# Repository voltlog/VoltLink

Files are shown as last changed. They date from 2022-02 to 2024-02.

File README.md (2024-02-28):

# VoltLink™
***If you would like to order one of these adapters ready assembled, check out my [Tindie store](https://www.tindie.com/products/23076/).***

VoltLink™ is a USB to serial adapter board based on the popular CP2102N chip with built-in ESP32 auto-reset circuitry. When compared to the cheap modules you can get from Aliexpress this adapter is reliable & flexible at the same time. Reliable because it's based on a well known usb to serial adapter chip sourced from a known supplier and flexible because you have the ESP32 IO & EN pin auto-reset circuit built-in so there is no need to implement this on the target board.

Another advantage of the VoltLink is the built-in 3.3V 500mA low dropout regulator capable of powering the device your are programming. Optionally you can connect a custom JST cable that alows programming of Shelly relays safely, without mains power. This makes the VoltLink one of the best usb/serial adapters to flash your devices with Tasmota or ESPHome.

You have the option of connecting through the VoltLink connector which is a JST-SH 1.0mm pitch 6 pin connector that saves space on the target board or via standard 0.1 inch pin header. 

More info about this project in [Voltlog #405](https://youtu.be/4uZt7zaJOnc).
> Please note, there have been several board revisions since I made that video.

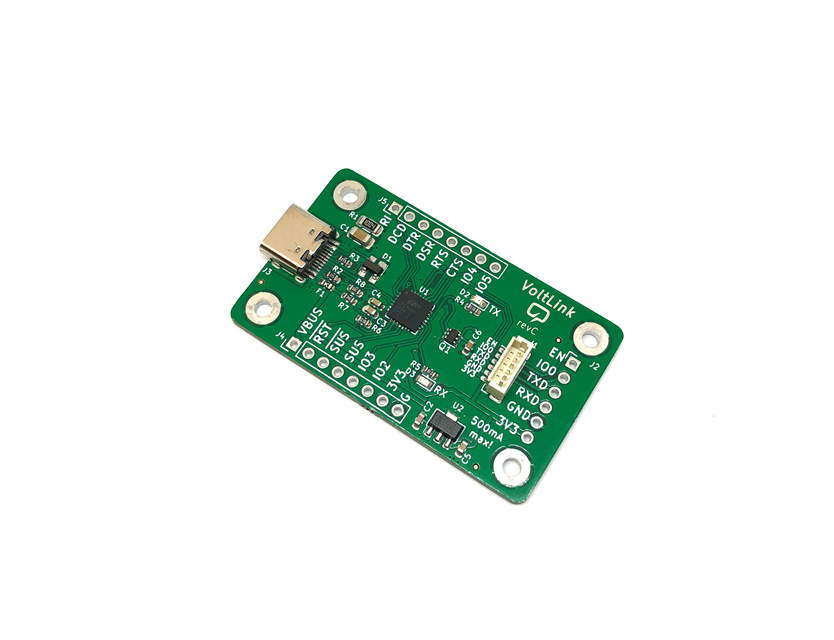
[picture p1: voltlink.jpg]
Image of the assembled PCB


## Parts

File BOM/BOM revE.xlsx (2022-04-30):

VoltLink revD Bill Of Materials
Qty | Reference(s) | Value | Footprint | Datasheet | LCSC | PN
1 | C1 | 4.7nF | Capacitor_SMD:C_1206_3216Metric | ~ | C107198 | CC1206KKX7RCBB472
2 | C2, C4 | 1uF | Capacitor_SMD:C_0603_1608Metric | ~ | C1592 | CL10A105KO8NNNC
2 | C3, C5 | 10uF | Capacitor_SMD:C_0603_1608Metric | ~ | C92487 | CL10A106MO8NQNC
1 | C6 | 0.1uF | Capacitor_SMD:C_0603_1608Metric | ~ | C24452 | CL10B104JB8NNNC
1 | D1 | PWR | LED_SMD:LED_0603_1608Metric | https://datasheet.lcsc.com/lcsc/2008201033_Foshan-NationStar-Optoelectronics-NCD0603R5_C193902.pdf | C193902 | NCD0603R5
1 | D2 | TX | LED_SMD:LED_0603_1608Metric | https://datasheet.lcsc.com/lcsc/2008201032_Foshan-NationStar-Optoelectronics-NCD0603G1_C84267.pdf | C84267 | NCD0603G1
1 | D3 | RX | LED_SMD:LED_0603_1608Metric | https://datasheet.lcsc.com/lcsc/2008201033_Foshan-NationStar-Optoelectronics-NCD0603R5_C193902.pdf | C193902 | NCD0603R5
1 | F1 | 0.5A | Fuse:Fuse_0603_1608Metric | ~ | C207014 | 0603L050SLYR
1 | J1 | Link | Connector_JST:JST_SH_BM06B-SRSS-TB_1x06-1MP_P1.00mm_Vertical | ~ | C145963 | BOOMELE
1 | J2 | Standard | Connector_PinHeader_2.54mm:PinHeader_1x06_P2.54mm_Horizontal | ~
1 | J3 | USB_C_Receptacle_USB2.0 | voltlog:TYPE-C-31-M-12 | https://www.usb.org/sites/default/files/documents/usb_type-c.zip | C165948 | TYPE-C-31-M-12
2 | J4, J5 | Conn_01x08 | Connector_PinHeader_2.54mm:PinHeader_1x08_P2.54mm_Vertical | ~
1 | Q1 | UMH3N | Package_TO_SOT_SMD:SOT-363_SC-70-6 | http://rohmfs.rohm.com/en/products/databook/datasheet/discrete/transistor/digital/emh3t2r-e.pdf | C62892 | UMH3N
1 | R1 | 1M | Resistor_SMD:R_1206_3216Metric | ~
2 | R2, R3 | 5K1 | Resistor_SMD:R_0603_1608Metric | ~
1 | R4 | 22.1K | Resistor_SMD:R_0603_1608Metric | ~
1 | R5 | 47.5K | Resistor_SMD:R_0603_1608Metric | ~
1 | RN1 | 1K | Resistor_SMD:R_Array_Convex_4x0603 | ~ | C425239 | 4D03WGF1001T5E
1 | U1 | LR1107 | Package_TO_SOT_SMD:SOT-89-3 | https://datasheet.lcsc.com/lcsc/1809251634_UTC-Unisonic-Tech-LR1107G-33-AB3-C-R_C171498.pdf | C171498 | LR1107G-33-AB3-C-R
1 | U2 | USBLC6-2P6 | Package_TO_SOT_SMD:SOT-666 | https://www.st.com/resource/en/datasheet/usblc6-2.pdf
1 | U3 | CP2102N-A01-GQFN28 | Package_DFN_QFN:QFN-28-1EP_5x5mm_P0.5mm_EP3.35x3.35mm | https://www.silabs.com/documents/public/data-sheets/cp2102n-datasheet.pdf | C964632 | CP2102N-A02-GQFN28R

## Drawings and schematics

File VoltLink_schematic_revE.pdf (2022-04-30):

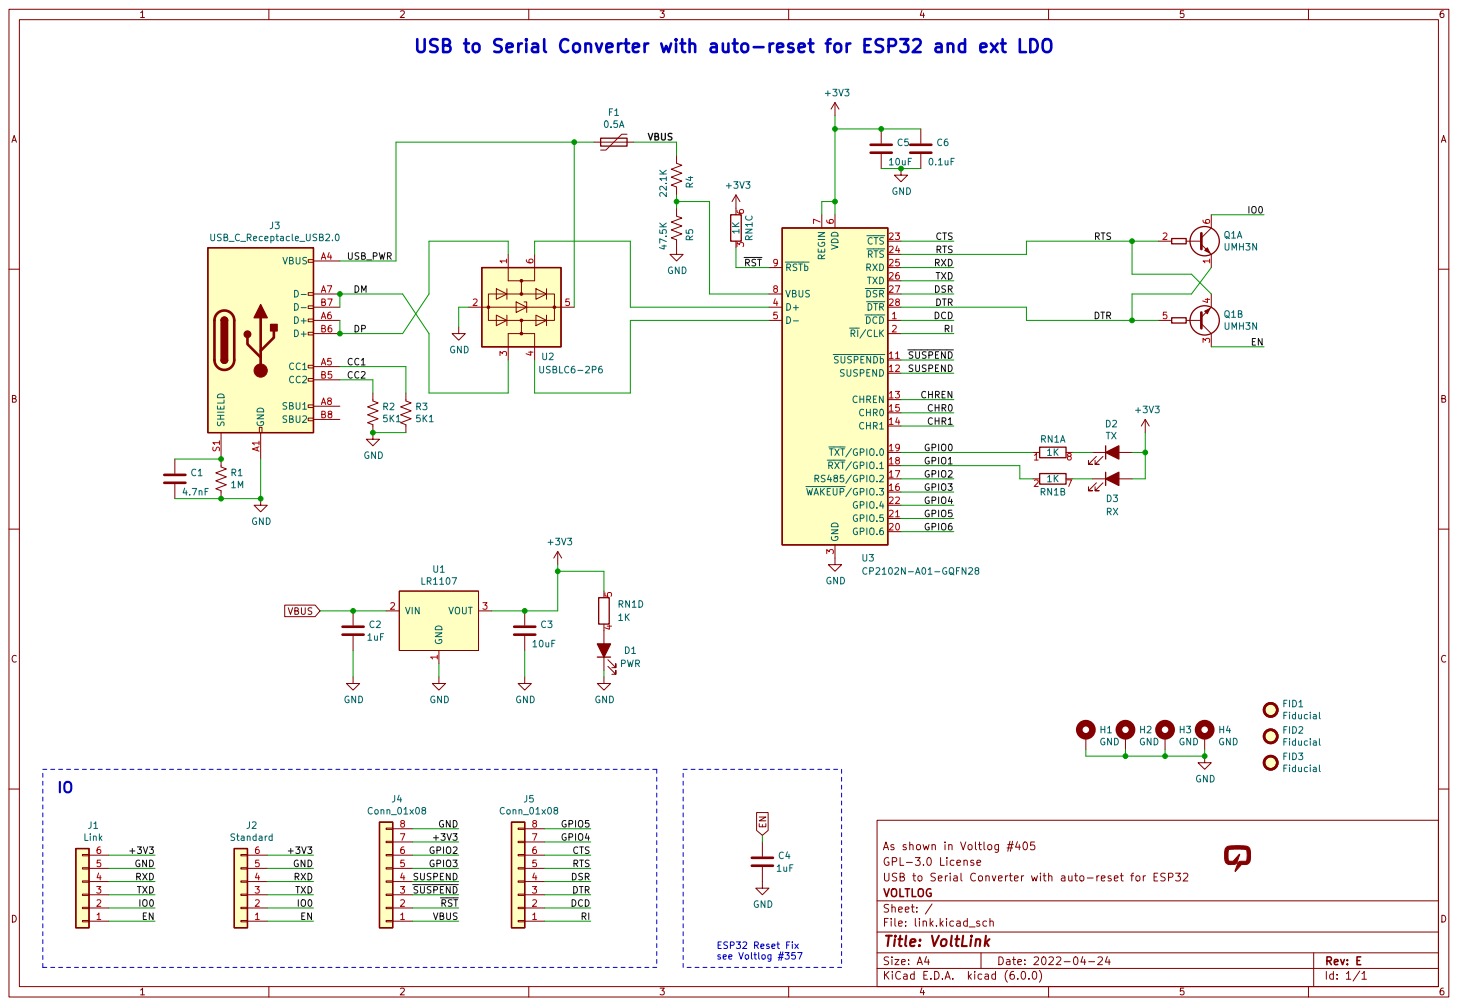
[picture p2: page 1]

USB to Serial Converter with auto-reset for ESP32 and ext LDO

USB to Serial Converter with auto-reset for ESP32 GPL-3.0 License As shown in Voltlog #405

4 | 4 SUSPEND | 4
2 | VBUS 2 | DTR 2

File: link.kicad_sch Sheet: / VOLTLOG

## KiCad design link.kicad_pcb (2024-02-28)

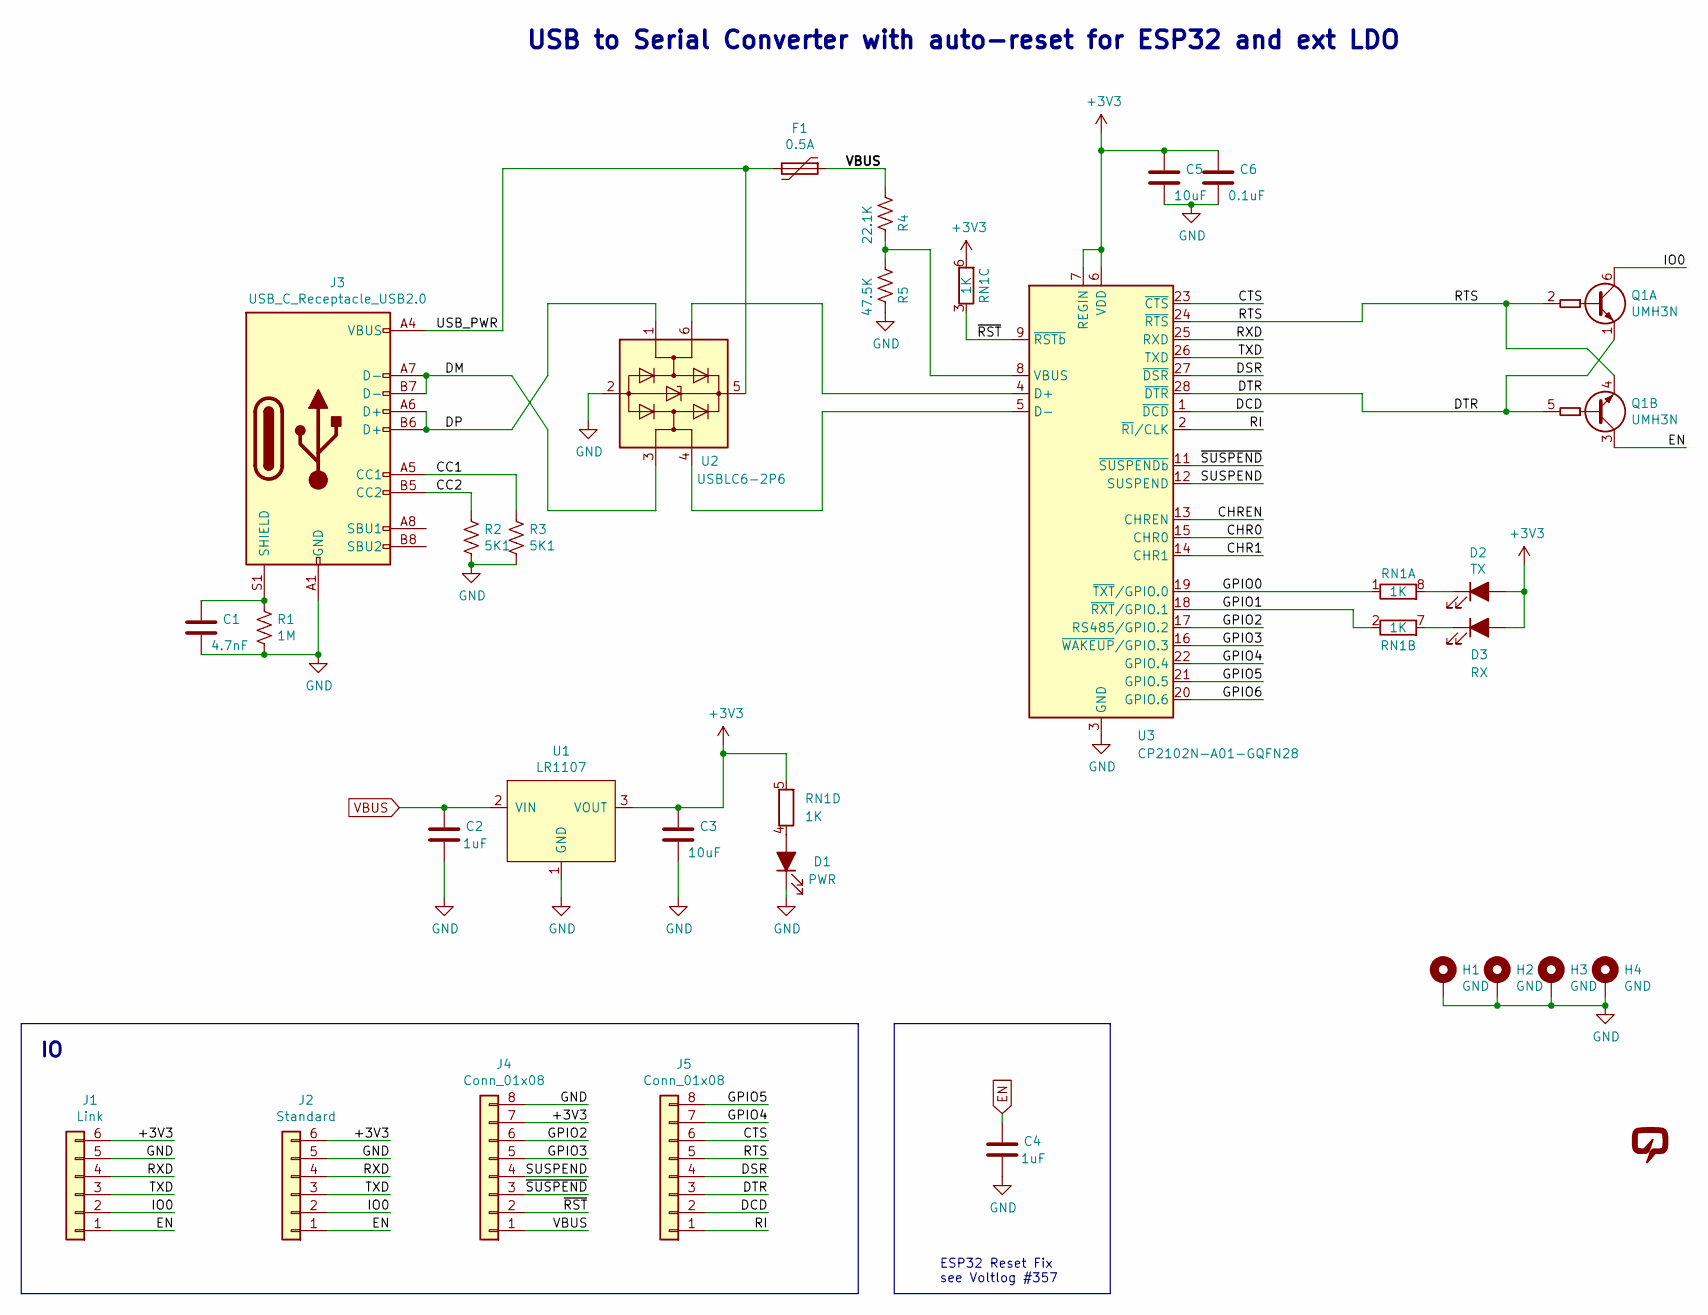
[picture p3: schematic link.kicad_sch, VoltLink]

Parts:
C1: 4.7nF; C_1206_3216Metric; Voltage 1KV; LCSC C107198
C2, C4: 1uF; C_0603_1608Metric; LCSC C15849
C3: 10uF; C_0603_1608Metric; Voltage 16V; LCSC C19702
C5: 10uF; C_0603_1608Metric; LCSC C19702
C6: 0.1uF; C_0603_1608Metric; LCSC C14663
D1: PWR; LED_0603_1608Metric; LCSC C193902
D2: TX; LED_0603_1608Metric; LCSC C84267
D3: RX; LED_0603_1608Metric; LCSC C193902
F1: 0.5A; Fuse_0603_1608Metric; LCSC C207014
H1, H2, H3, H4: GND; MountingHole_2.5mm_Pad
J1: Link; JST_SH_BM06B-SRSS-TB_1x06-1MP_P1.00mm_Vertical; LCSC C145963
J2: Standard; PinHeader_1x06_P2.54mm_Horizontal
J3: USB_C_Receptacle_USB2.0; TYPE-C-31-M-12; LCSC C165948
J4, J5: Conn_01x08; PinHeader_1x08_P2.54mm_Vertical
Q1: UMH3N; SOT-363_SC-70-6; LCSC C62892
R1: 1M; R_1206_3216Metric
R2, R3: 5K1; R_0603_1608Metric
R4: 22.1K; R_0603_1608Metric; LCSC C25961
R5: 47.5K; R_0603_1608Metric; LCSC C203634
RN1: 1K; R_Array_Convex_4x0603; LCSC C20197
U1: LR1107; SOT-89-3; LCSC C171498
U2: USBLC6-2P6; SOT-666; LCSC C2827693
U3: CP2102N-A01-GQFN28; QFN-28-1EP_5x5mm_P0.5mm_EP3.35x3.35mm; LCSC C1550553
V1: VOLTLOG_LOGO; voltlog_mask_3mm

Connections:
+3V3: C3.1, C5.1, C6.1, D2.2 (A), D3.2 (A), J1.6, J2.6, J4.7, RN1.5 (R4.2), RN1.6 (R3.2), U1.3 (VOUT), U3.6 (VDD), U3.7 (REGIN)
/CC1: J3.A5 (CC1), R3.1
/CC2: J3.B5 (CC2), R2.1
/CHR0: U3.15 (CHR0)
/CHR1: U3.14 (CHR1)
/CHREN: U3.13 (CHREN)
/CTS: J5.6, U3.23 (~CTS)
/DCD: J5.2, U3.1 (~DCD)
/DM: J3.A7 (D-), J3.B7 (D-), U2.3 (I/O2)
/DP: J3.A6 (D+), J3.B6 (D+), U2.1 (I/O1)
/DSR: J5.4, U3.27 (~DSR)
/DTR: J5.3, Q1.1 (E1), Q1.5 (B2), U3.28 (~DTR)
/GPIO0: RN1.1 (R1.1), U3.19 (~TXT/GPIO.0)
/GPIO1: RN1.2 (R2.1), U3.18 (~RXT/GPIO.1)
/GPIO2: J4.6, U3.17 (RS485/GPIO.2)
/GPIO3: J4.5, U3.16 (~WAKEUP/GPIO.3)
/GPIO4: J5.7, U3.22 (GPIO.4)
/GPIO5: J5.8, U3.21 (GPIO.5)
/GPIO6: U3.20 (GPIO.6)
/IO0: J1.2, J2.2, Q1.6 (C1)
/RI: J5.1, U3.2 (~RI/CLK)
/RTS: J5.5, Q1.2 (B1), Q1.4 (E2), U3.24 (~RTS)
/RXD: J1.4, J2.4, U3.25 (RXD)
/SUSPEND: J4.4, U3.12 (SUSPEND)
/TXD: J1.3, J2.3, U3.26 (TXD)
/USB_PWR: F1.2, J3.A4 (VBUS), J3.A9 (VBUS), J3.B4 (VBUS), J3.B9 (VBUS), U2.5 (VBUS)
/~RST: J4.2, RN1.3 (R3.1), U3.9 (~RSTb)
/~SUSPEND: J4.3, U3.11 (~SUSPENDb)
EN: C4.1, J1.1, J2.1, Q1.3 (C2)
GND: C1.2, C2.2, C3.2, C4.2, C5.2, C6.2, D1.1 (K), H1.1, H2.1, H3.1, H4.1, J1.5, J2.5, J3.A1 (GND), J3.A12 (GND), J3.B1 (GND), J3.B12 (GND), J4.8, R1.2, R2.2, R3.2, R5.2, U1.1 (GND), U2.2 (GND), U3.3 (GND), U3.29 (GND)
unnamed: C1.1, J3.S1 (SHIELD), R1.1
unnamed: D1.2 (A), RN1.4 (R4.1)
unnamed: D2.1 (K), RN1.8 (R1.2)
unnamed: D3.1 (K), RN1.7 (R2.2)
unnamed: R4.2, R5.1, U3.8 (VBUS)
unnamed: U2.4 (I/O2), U3.5 (D-)
unnamed: U2.6 (I/O1), U3.4 (D+)
VBUS: C2.1, F1.1, J4.1, R4.1, U1.2 (VIN)

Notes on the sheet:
ESP32 Reset Fix see Voltlog #357
USB to Serial Converter with auto-reset for ESP32 and ext LDO

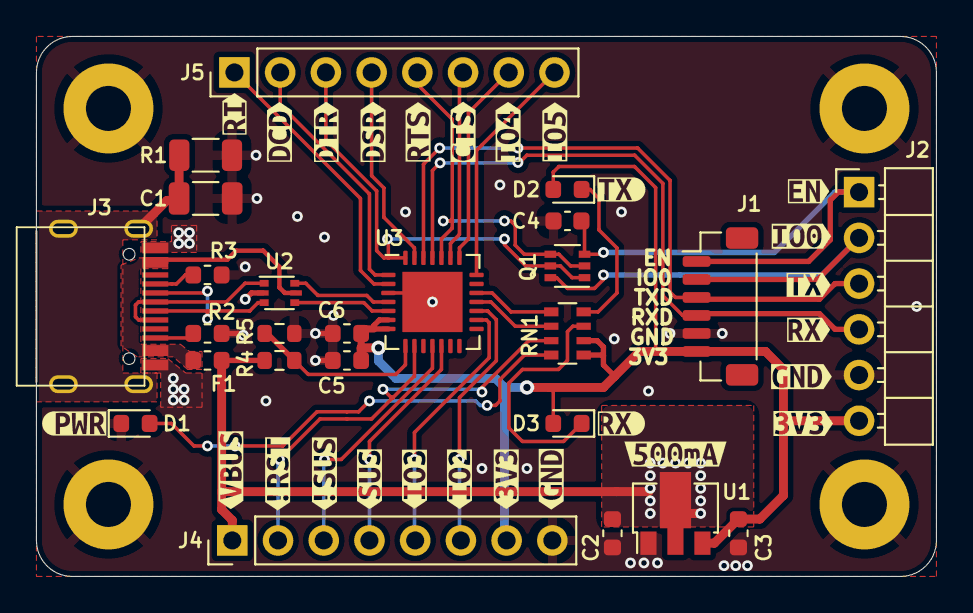
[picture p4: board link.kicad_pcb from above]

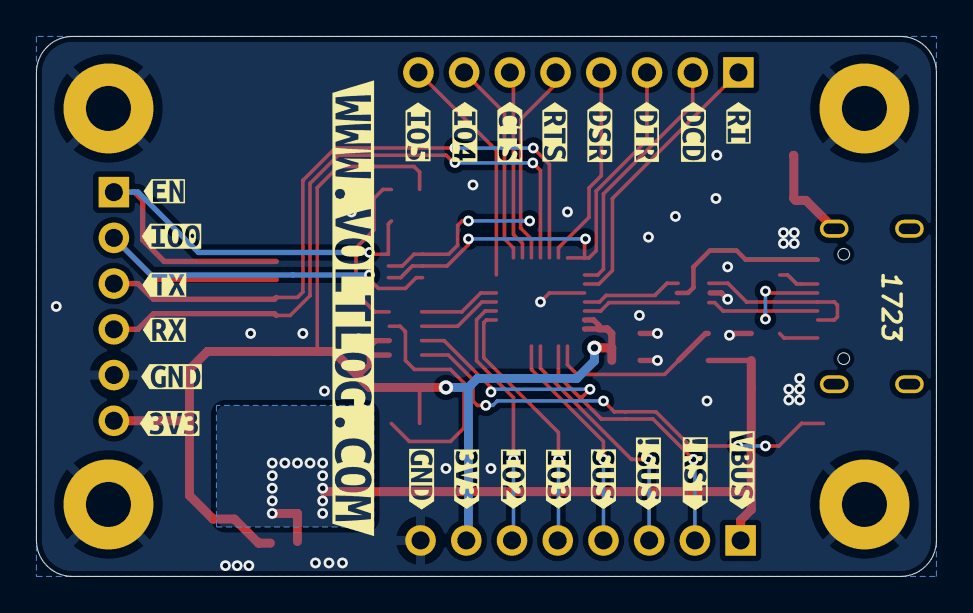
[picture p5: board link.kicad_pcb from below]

Board: 2 copper layers, 50.0 x 30.0 mm, 79 parts (23 on the bottom side), 34 nets.

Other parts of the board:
kibuzzard-62357A06: G***; kibuzzard-62357A06
kibuzzard-62357A8A: G***; kibuzzard-62357A8A
kibuzzard-62357A41: G***; kibuzzard-62357A41
kibuzzard-62357AC8: G***; kibuzzard-62357AC8
kibuzzard-62357AF5: G***; kibuzzard-62357AF5
kibuzzard-62357B6B: G***; kibuzzard-62357B6B
kibuzzard-62357B8F: G***; kibuzzard-62357B8F
kibuzzard-62357B09: G***; kibuzzard-62357B09
kibuzzard-62357B9D: G***; kibuzzard-62357B9D
kibuzzard-62357B18: G***; kibuzzard-62357B18
kibuzzard-62357B23: G***; kibuzzard-62357B23
kibuzzard-62357B61: G***; kibuzzard-62357B61
kibuzzard-62357B85: G***; kibuzzard-62357B85
kibuzzard-62357B96: G***; kibuzzard-62357B96
kibuzzard-62357BA3: G***; kibuzzard-62357BA3
kibuzzard-62357BA9: G***; kibuzzard-62357BA9
kibuzzard-62357BE4: G***; kibuzzard-62357BE4
kibuzzard-62357BED: G***; kibuzzard-62357BED
kibuzzard-62357BF2: G***; kibuzzard-62357BF2
kibuzzard-62357BF8: G***; kibuzzard-62357BF8
kibuzzard-62357BFE: G***; kibuzzard-62357BFE
kibuzzard-62357C0A: G***; kibuzzard-62357C0A
kibuzzard-62357C11: G***; kibuzzard-62357C11
kibuzzard-62357C18: G***; kibuzzard-62357C18
kibuzzard-623575FB: G***; kibuzzard-623575FB
kibuzzard-623576E7: G***; kibuzzard-623576E7
kibuzzard-623576F6: G***; kibuzzard-623576F6
kibuzzard-623577BD: G***; kibuzzard-623577BD
kibuzzard-623577CF: G***; kibuzzard-623577CF
kibuzzard-623577DC: G***; kibuzzard-623577DC
kibuzzard-623577E9: G***; kibuzzard-623577E9
kibuzzard-623577F4: G***; kibuzzard-623577F4
kibuzzard-623578AD: G***; kibuzzard-623578AD
kibuzzard-623578BA: G***; kibuzzard-623578BA
kibuzzard-623579BD: G***; kibuzzard-623579BD
kibuzzard-623579CB: G***; kibuzzard-623579CB
kibuzzard-623579D6: G***; kibuzzard-623579D6
kibuzzard-623579E1: G***; kibuzzard-623579E1
kibuzzard-623579ED: G***; kibuzzard-623579ED
kibuzzard-623579F4: G***; kibuzzard-623579F4
kibuzzard-623579FF: G***; kibuzzard-623579FF
kibuzzard-6235760A: G***; kibuzzard-6235760A
kibuzzard-62357631: G***; kibuzzard-62357631
kibuzzard-62357705: G***; kibuzzard-62357705
kibuzzard-62357716: G***; kibuzzard-62357716
kibuzzard-62357727: G***; kibuzzard-62357727
kibuzzard-62357731: G***; kibuzzard-62357731
kibuzzard-62357776: G***; kibuzzard-62357776
kibuzzard-62357894: G***; kibuzzard-62357894

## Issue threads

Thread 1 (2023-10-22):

Feature request - program devices without reset pin

angelnu, 2023-10-22:
First thanks a lot for the wonderful programmer - I ordered a couple and they have become my default programmer.

I would like to ask for an improvement when flashing devices that do not have a reset pin. Currently I deal with them by connecting the gpio0 pin to GND (I soldered a Pin to the VoltLink to make it easier) and then connect the USB. While this works it is not ideal as afterwards I have to disconnect the GPIO0 from GND and then re-connect the power to get a reset.

Would it be possible to have the 3.3 voltage output to follow the EN pin and so force the esp32 to reset?

voltlog, 2023-10-23:
Hey! Happy to hear you like the Voltlink!

**Having the 3.3V rail follow any other signal would be a bad idea as that would potentially put a variety of devices into unknown states.  Most devices rely on that 3V3 rail being present while EN/IO0 are toggled.**

As a simple workaround I would suggest installing a momentary NC switch on your 3V3 line between VoltLink and target so you can toggle it manually.

Closed 2023-10-23.

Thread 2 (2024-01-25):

Invalid header error on Sonoff Zigbee bridge

MagicienFr, 2024-01-25:
Also the device is working very fine on Sonoff basic, I canot tasmotize the zbbridge with the device. The invalid header error is raised everytime.
Also, the "self reseting" feature of tasmotizer windows 10 application doesn't seem to work: I use manual ground on IO0 to set the device in flash mode.

Does anybody have an advice?

Patrick

voltlog, 2024-01-25:
This issue has nothing to do with the VoltLink.
I suggest using the tasmota web installer, that works fine for me.

voltlog, 2024-01-26:
@MagicienFr The Sonoff zbbridge is not a good idea to start with, I have used in the past and it has poor performance. You should use a zigbee dongle plugged directly into HomeAssistant. The SONOFF ZBDongle-P should be a good start.

Closed 2024-01-25.

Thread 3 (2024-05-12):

setup for Mac M1 - No compatible devices found.

roger-richards, 2024-05-12:
Bought a VoltLink and trying to use it with my Mac M1 Pro.  I downloaded the Silicon Labs "CP210x USB to UART Bridge VCP Drivers" for mac and installed, had to unblock the driver in System Preferences Security & Privacy pane.  If I run the following command in term: system_profiler SPUSBDataType
```
    USB 3.1 Bus:
      Host Controller Driver: AppleT6000USBXHCI

    USB 3.1 Bus:
      Host Controller Driver: AppleT6000USBXHCI

    USB 3.1 Bus:
      Host Controller Driver: AppleT6000USBXHCI
        VoltLink CP2102N USB to UART Bridge:
          Product ID: 0xea60
          Vendor ID: 0x10c4  (Silicon Laboratories, Inc.)
          Version: 1.00
          Serial Number: 8cd45e9f6754ed118fe443f71c62bc44
          Speed: Up to 12 Mb/s
          Manufacturer: Silicon Labs
          Location ID: 0x00100000 / 1
          Current Available (mA): 500
          Current Required (mA): 500
          Extra Operating Current (mA): 0
```
So the VoltLink shows connected to my Mac.
When I try to use the Tasmota web installer or ESP-Flasher-macOSarm.app both of them say **no compatible devices found.**  I've confirmed that USB Serial connections are not blocked in Chrome. Also tried Edge.  Searched for a solution with no luck.  Do you have any recommendations?

Did a bit more searching and someone reported a conflict after installing the Silicon Labs driver (since recent MacOS has a driver included.)  I uninstalled the Silicon Labs driver and still have my problem.  VoltLink shows up when connected but no app can detect the port.

roger-richards, 2024-05-13:
Having installed and uninstalled the Silicon Labs driver twice, I decided to borrow a friend's MacBook M1 Air and web tasmotizer programmer worked immediately (no additional driver installed.) There is something about my MacBook M1 Pro that is preventing the various tasmotizer programmers from "seeing" the device (even though MacOS shows it is present.) Real mystery, but I have my tasmota device programmed and can finish my project.  If I find out what is blocking the programmer on my MacBook, I'll update this Issue. Closing for now.

roger-richards, 2024-05-13:
If I find out what is blocking the programmer on my MacBook, I'll update this Issue. Closing for now

voltlog, 2024-05-14:
@roger-richards Thanks! I'm looking into this as well by asking some friends with M processors to run some tests. I don't have any experience with MacOS and I'm generally noob level with Linux so I can't provide any help with debugging your particular issue. I'm just gonna try to confirm it's working on other setups.

Closed 2024-05-13.

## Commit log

2021-03-15 Initial commit of files
    [Voltlink_BOM_revA.csv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]
2021-03-15 Added board image
2021-10-05 Added image of the board
2022-02-14 Release revC
    [BOM.csv, Voltlink_BOM_revA.csv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]
2022-02-14 removed kicad backups
2022-02-14 Added PCB image
2022-04-24 release revD
    [BOM revD.xlsx, BOM.csv]
2022-04-30 Release revE
    [BOM revD.xlsx, BOM revE.xlsx, link.kicad_pcb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]
2022-04-30 removed old files
    [link.sch]
2024-02-28 revE release
    [centroid_revE.csv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]
